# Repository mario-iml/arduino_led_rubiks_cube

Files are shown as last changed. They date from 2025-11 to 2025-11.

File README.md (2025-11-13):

# arduino_led_rubiks_cube
Disclaimer: This was in 2019, and we didn't even know about Git yet, so we had to scrape together Code and PCB files from old chats. We take no guarantee that this works and is up-to-date :).

## Description
Arduino based LED Rubik's Cube. 
This Project was made as a High-school Project with two other Students. To achieve this, we had to:
- Design of PCB's encompassing the buttons, LED's and shift registers with EAGLE
- Designing and Printing of the cubes case
- Assembling and Wirering the PCB's and Arduino
- Write the Code in Arduino IDE with C++

## Problems we encountered
- We were all pretty new to Computer Science and Electrical Engineering. We made many mistakes but learned many things in the process.
- We accidentally ordered the wrong type of LEDs (common anode instead of common cathode) for the PCB without realizing it. In the end, we had to desolder some of the LEDs again :(
- There were mistakes in the first version of the PCB design, which caused us to get dangerously close to the deadline due to long delivery times.

## PCB designs
The PCBs were designed with the Eagle software. Design files can be found in the Repo and here are some Screenshots:





## Other Images






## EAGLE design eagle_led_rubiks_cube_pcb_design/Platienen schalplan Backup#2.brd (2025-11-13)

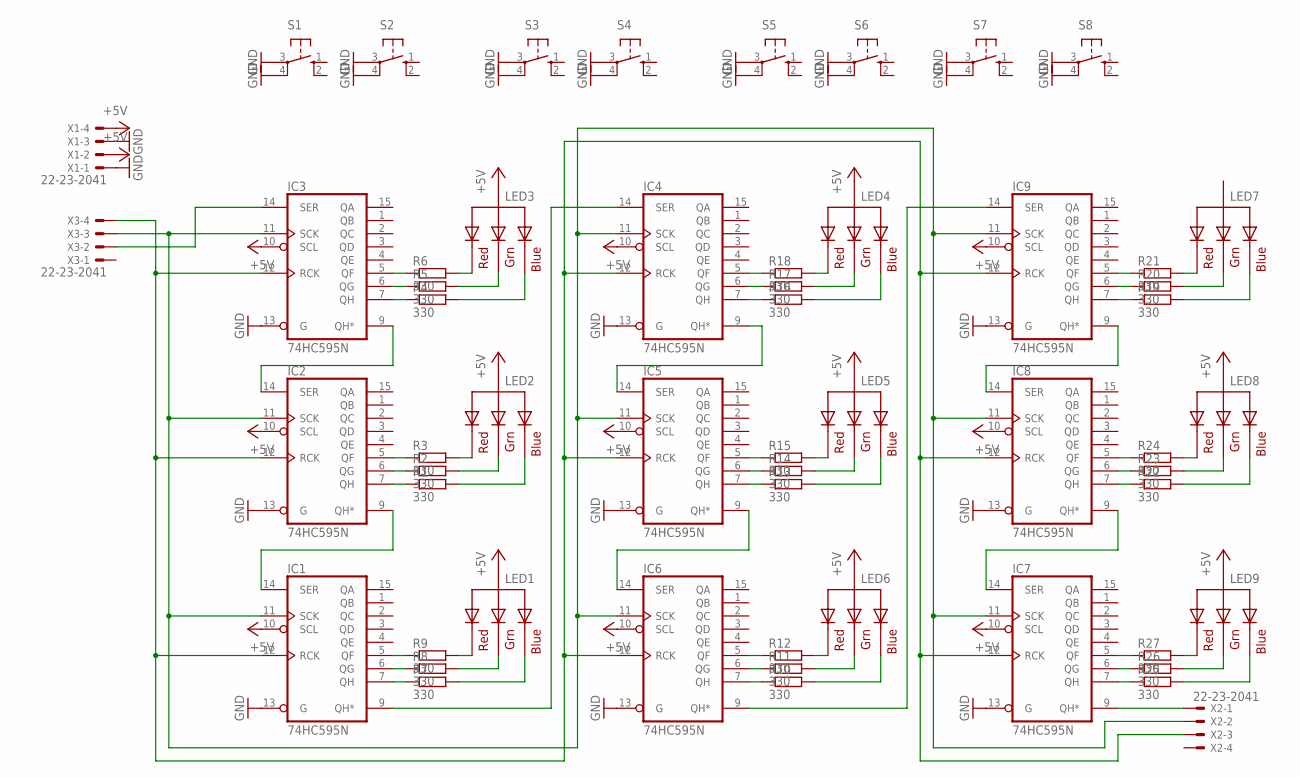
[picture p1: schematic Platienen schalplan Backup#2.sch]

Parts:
IC1, IC2, IC3, IC4, IC5, IC6, IC7, IC8, IC9: 74HC595N; DIL16
LED1, LED2, LED3, LED4, LED5, LED6, LED7, LED8, LED9: RGBLED_CA-5MM; LED5MMRGB
R1, R2, R3, R4, R5, R6, R7, R8, R9, R10, R11, R12, R13, R14, R15, R16, R17, R18, R19, R20, R21, R22, R23, R24, R25, R26, R27: 330; 0204/5
S1, S2, S3, S4, S5, S6, S7, S8: 10-XX; B3F-10XX
X1, X2, X3: 22-23-2041

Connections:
+5V: IC1.10 (SCL), IC2.10 (SCL), IC3.10 (SCL), IC4.10 (SCL), IC5.10 (SCL), IC6.10 (SCL), IC7.10 (SCL), IC8.10 (SCL), IC9.10 (SCL), LED1.2 (VCC), LED2.2 (VCC), LED3.2 (VCC), LED4.2 (VCC), LED5.2 (VCC), LED6.2 (VCC), LED8.2 (VCC), LED9.2 (VCC), X1.2, X1.4
GND: IC1.8 (GND), IC1.13 (G), IC2.8 (GND), IC2.13 (G), IC3.8 (GND), IC3.13 (G), IC4.8 (GND), IC4.13 (G), IC5.8 (GND), IC5.13 (G), IC6.8 (GND), IC6.13 (G), IC7.8 (GND), IC7.13 (G), IC8.8 (GND), IC8.13 (G), IC9.8 (GND), IC9.13 (G), S1.3, S1.4 (P1), S2.3, S2.4 (P1), S3.3, S3.4 (P1), S4.3, S4.4 (P1), S5.3, S5.4 (P1), S6.3, S6.4 (P1), S7.3, S7.4 (P1), S8.3, S8.4 (P1), X1.1, X1.3
unnamed: IC3.7 (QH), R4.1
unnamed: IC3.6 (QG), R5.1
unnamed: IC3.5 (QF), R6.1
unnamed: LED5.1 (RED), R15.2
unnamed: LED4.1 (RED), R18.2
unnamed: LED7.1 (RED), R21.2
unnamed: IC2.7 (QH), R1.1
unnamed: IC2.6 (QG), R2.1
unnamed: IC2.5 (QF), R3.1
unnamed: IC1.5 (QF), R9.1
unnamed: IC1.6 (QG), R8.1
unnamed: IC1.7 (QH), R7.1
unnamed: LED7.3 (GREEN), R20.2
unnamed: LED7.4 (BLUE), R19.2
unnamed: LED8.1 (RED), R24.2
unnamed: LED8.3 (GREEN), R23.2
unnamed: LED8.4 (BLUE), R22.2
unnamed: LED9.1 (RED), R27.2
unnamed: IC6.7 (QH), R10.1
unnamed: IC6.6 (QG), R11.1
unnamed: IC6.5 (QF), R12.1
unnamed: LED9.3 (GREEN), R26.2
unnamed: LED9.4 (BLUE), R25.2
unnamed: LED6.1 (RED), R12.2
unnamed: IC5.7 (QH), R13.1
unnamed: IC5.6 (QG), R14.1
unnamed: IC5.5 (QF), R15.1
unnamed: LED6.3 (GREEN), R11.2
unnamed: LED6.4 (BLUE), R10.2
unnamed: LED5.3 (GREEN), R14.2
unnamed: IC4.7 (QH), R16.1
unnamed: IC4.6 (QG), R17.1
unnamed: IC4.5 (QF), R18.1
unnamed: LED5.4 (BLUE), R13.2
unnamed: LED4.3 (GREEN), R17.2
unnamed: LED4.4 (BLUE), R16.2
unnamed: IC9.7 (QH), R19.1
unnamed: IC9.6 (QG), R20.1
unnamed: IC9.5 (QF), R21.1
unnamed: IC8.5 (QF), R24.1
unnamed: IC8.6 (QG), R23.1
unnamed: IC8.7 (QH), R22.1
unnamed: IC7.5 (QF), R27.1
unnamed: IC7.6 (QG), R26.1
unnamed: IC7.7 (QH), R25.1
unnamed: LED2.1 (RED), R3.2
unnamed: LED2.3 (GREEN), R2.2
unnamed: LED2.4 (BLUE), R1.2
unnamed: LED1.1 (RED), R9.2
unnamed: LED1.3 (GREEN), R8.2
unnamed: LED1.4 (BLUE), R7.2
unnamed: LED3.1 (RED), R6.2
unnamed: LED3.3 (GREEN), R5.2
unnamed: IC2.14 (SER), IC3.9 (QH*)
unnamed: IC1.14 (SER), IC2.9 (QH*)
unnamed: IC1.9 (QH*), IC4.14 (SER)
unnamed: IC4.9 (QH*), IC5.14 (SER)
unnamed: IC5.9 (QH*), IC6.14 (SER)
unnamed: IC6.9 (QH*), IC9.14 (SER)
unnamed: IC8.14 (SER), IC9.9 (QH*)
unnamed: IC7.14 (SER), IC8.9 (QH*)
unnamed: IC1.12 (RCK), IC2.12 (RCK), IC3.12 (RCK), IC4.12 (RCK), IC5.12 (RCK), IC6.12 (RCK), IC7.12 (RCK), IC8.12 (RCK), IC9.12 (RCK), X2.3, X3.4
unnamed: IC3.14 (SER), X3.2
unnamed: IC1.11 (SCK), IC2.11 (SCK), IC3.11 (SCK), IC4.11 (SCK), IC5.11 (SCK), IC6.11 (SCK), IC7.11 (SCK), IC8.11 (SCK), IC9.11 (SCK), X2.2, X3.3
unnamed: IC7.9 (QH*), X2.1
unnamed: LED3.4 (BLUE), R4.2
VCC: IC1.16 (VCC), IC2.16 (VCC), IC3.16 (VCC), IC4.16 (VCC), IC5.16 (VCC), IC6.16 (VCC), IC7.16 (VCC), IC8.16 (VCC), IC9.16 (VCC)

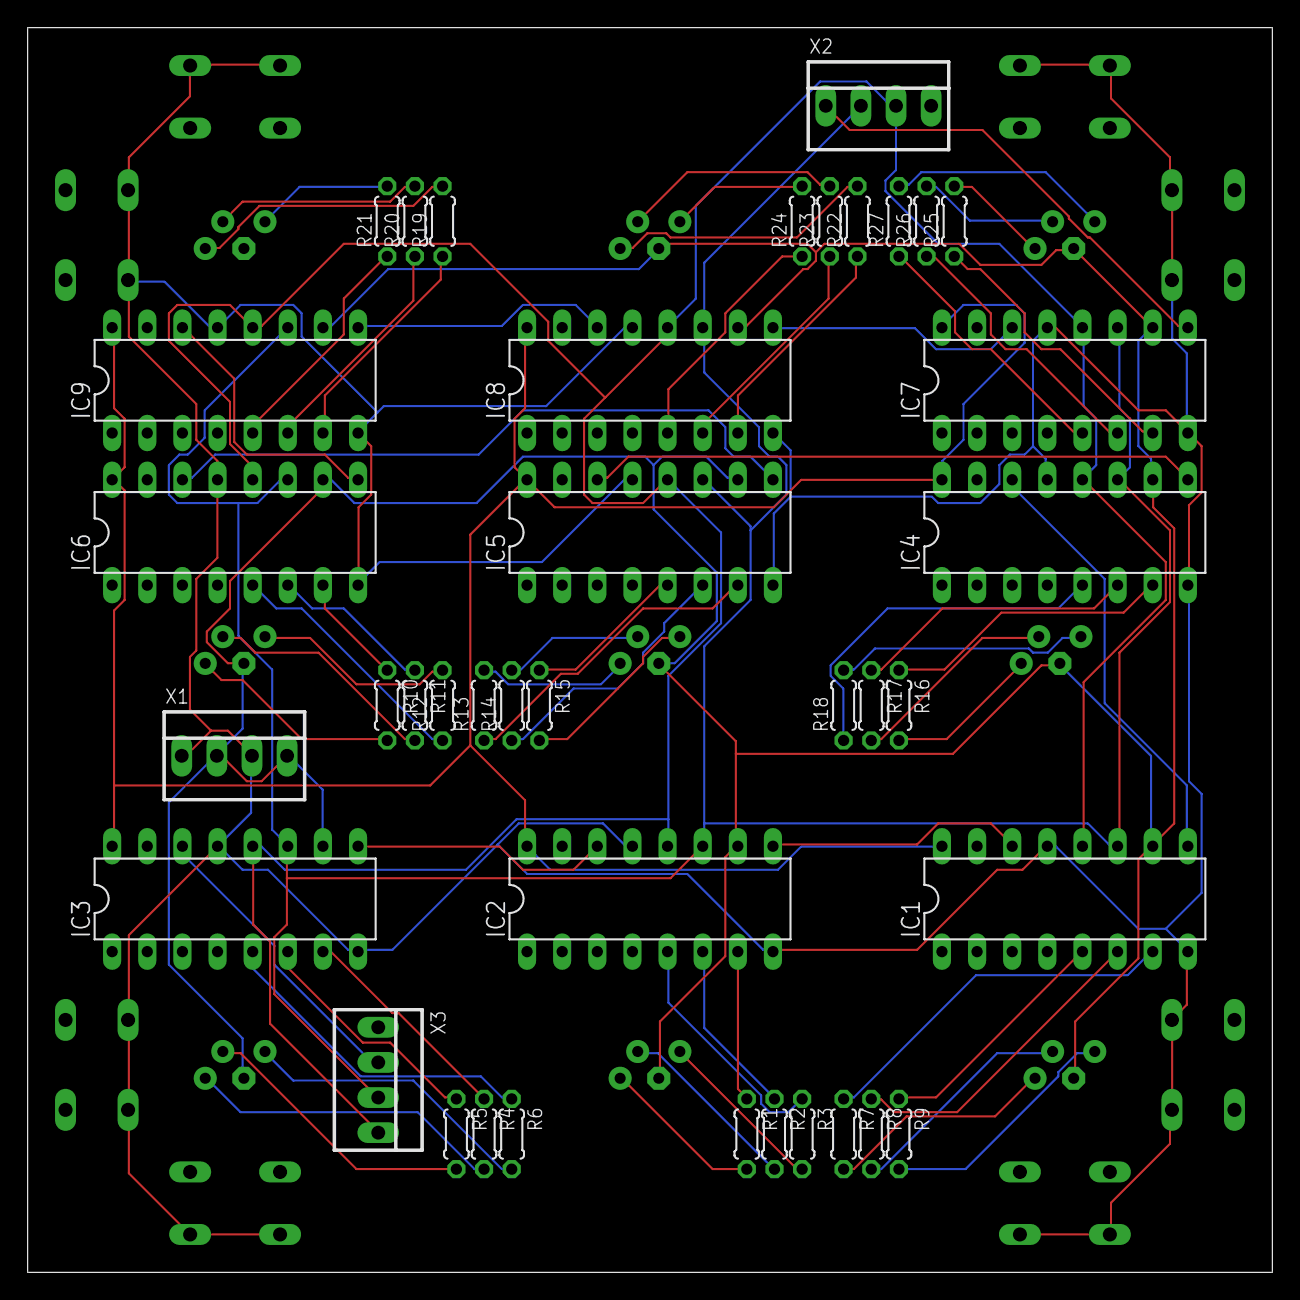
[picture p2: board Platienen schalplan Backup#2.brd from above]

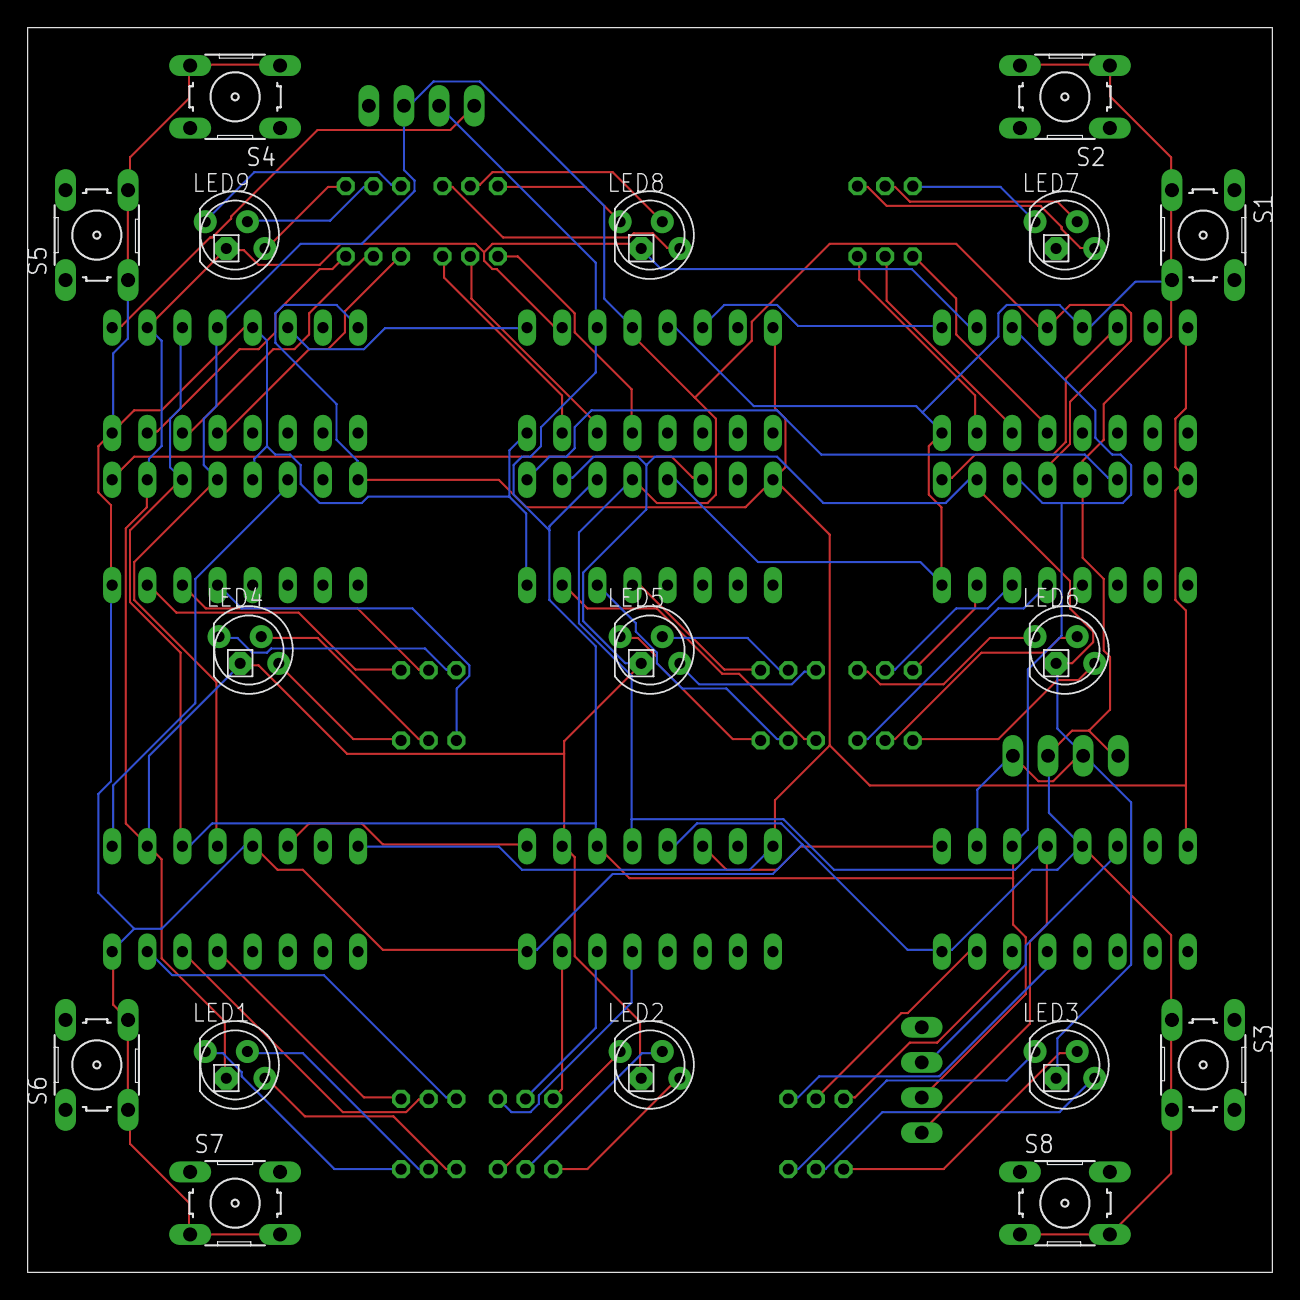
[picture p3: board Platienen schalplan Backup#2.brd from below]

Board: 2 copper layers, 90.0 x 90.0 mm, 56 parts (17 on the bottom side), 69 nets.

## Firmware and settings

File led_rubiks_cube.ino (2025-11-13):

// This code was recovered from a project documentation and IS NOT COMPLETE. We sadly dont have the whole code anymore
int datapin=11; //Pin 11 des Arduino ist an den data input(DS) des Schieberegisters angeschlossen
int clockpin=12; //Pin 12 des Arduino ist an den clock Pin(SH_CP) des Schieberegisters angeschlossen
int latchpin=8; //Pin 8 des Arduino ist an den latch Pin(ST_CP) des Schieberegisters angeschlossen

byte ledB=B011; //Farbe Blau
byte ledG=B101; //Farbe Grün
byte ledR=B110; //Farbe Rot
byte ledV=B010; //Farbe Violet
byte ledY=B100;  //Farbe Gelb
byte ledT=B001;  //Farbe Türkis
byte ledW=000;  //Farbe Weiß
byte led0=111;   //Farbe Aus

//Erstellen einer Array mit allen 54 LEDs und deren standardmäßig sortierter Anordnung, diese wird dann bei den Knopfdrücken verändert z.B. leds[54] = leds[53]
byte leds[]={ledR,ledR,ledR,ledR,ledR,ledR,ledR,ledR,ledR,ledW,ledW,ledW,ledW,ledW,ledW,ledW,ledW,ledW,ledB,ledB,ledB,ledB,ledB,ledB,ledB,ledB,ledB,ledG,ledG,ledG,ledG,ledG,ledG,ledG,ledG,ledG,ledY,ledY,ledY,ledY,ledY,ledY,ledY,ledY,ledY,ledV,ledV,ledV,ledV,ledV,ledV,ledV,ledV,ledV};

//Temporäre Variablen für den Tausch der leds
byte t0=leds[45],t1=leds[46],t2=leds[47],t3=leds[48],t4=leds[49],t5=leds[50],t6=leds[51],t7=leds[52],t8=leds[53],b0=leds[36],b1=leds[37],b2=leds[38],b3=leds[39],b4=leds[40],b5=leds[41],b6=leds[42],b7=leds[43],b8=leds[44],d0=leds[27],d1=leds[28],d2=leds[29],d3=leds[30],d4=leds[31],d5=leds[32],d6=leds[33],d7=leds[34],d8=leds[35],l0=leds[18],l1=leds[19],l2=leds[20],l3=leds[21],l4=leds[22],l5=leds[23],l6=leds[24],l7=leds[25],l8=leds[26],f0=leds[9],f1=leds[10],f2=leds[11],f3=leds[12],f4=leds[13],f5=leds[14],f6=leds[15],f7=leds[16],f8=leds[17],r0=leds[0],r1=leds[1],r2=leds[2],r3=leds[3],r4=leds[4],r5=leds[5],r6=leds[6],r7=leds[7],r8=leds[8];

const int bpin[]={5,6,7,8,9,10,11,12,13,A0,A1,A2}; //Arry mit den verschiedenen möglichen Moves mit den Buttons

int wait=500; //variable für eine festgelegte Wartedauer(kann einfach für den gesamten Code verändert werden

void setup()
{

    pinMode(datapin, OUTPUT); //Pins auf Output stellen("Daten senden")
    pinMode(clockpin, OUTPUT); //Pins auf Output stellen("Daten senden") 
    pinMode(latchpin, OUTPUT); //Pins auf Output stellen("Daten senden")
 
    for (int i=0;i<12;i++) //Wird für alle 12 möglichen Moves widerholt
    {
        pinMode(bpin[i],INPUT); //bpin[i]/alle möglichen Pins für die Knöpfe auf INPUT, so können wir abfragen ob ein Signal kommt
        digitalWrite(bpin[i],HIGH); //bpin[i]/alle möglichen Pins für die Knöpfe werden auf HIGH gestellt
    }
 
    digitalWrite(latchpin, LOW); //Latch Pin auf LOW(aus), dass die Leds sich nicht ändern wärend neue Bits reingegeben werden
    for (int i=0; i<54;i++) //For Schleife(Der Vorgang wird für alle 54 LEDs/Schieberegister widerholt)
    { 
        shiftOut(datapin, clockpin, MSBFIRST, leds[i]);  //LEDs werde sortiert eingeschaltet(Cube geht an)
    }
    digitalWrite(latchpin, HIGH);  //Latch Pin auf HIGH(an), um die "änderungen anzuzeigen"
}

void loop()
{
    digitalWrite(latchpin,LOW);
    for(int i=0;i<54;i++) //Wird für alle 54 LEDs/Schieberegister widerholt
    { 
        shiftOut(datapin, clockpin, MSBFIRST, leds[i]); //ShiftOut Befehl wird durch loop jedes mal widerholt(somit werden Änderungen übernommen)
    }
    digitalWrite(latchpin, HIGH);

    for(int i=0;i<12;i++)
    {
        digitalWrite(bpin[i],HIGH); //Jeder mögliche Move wird nochmals auf HIGH gestellt
    }

    int b[12]; //12 Zusätzliche Variablen erstellen in denen der Status der Buttons gespeichert wird.
    for (int x=0;x<12;x++) //Schleife für jeden möglichen move
    {
        b[x]=digitalRead(bpin[x]); //Es wird der Wert in jeder Variable der Array ausgelesen
    }
    if(((b[0]==LOW))) //IF abfrage für einen move
    {
        //rotate left face CCW
        t0=leds[45],t1=leds[46],t2=leds[47],t3=leds[48],t4=leds[49],t5=leds[50],t6=leds[51],t7=leds[52],t8=leds[53],b0=leds[36],b1=leds[37],b2=leds[38],b3=leds[39],b4=leds[40],b5=leds[41],b6=leds[42],b7=leds[43],b8=leds[44],d0=leds[27],d1=leds[28],d2=leds[29],d3=leds[30],d4=leds[31],d5=leds[32],d6=leds[33],d7=leds[34],d8=leds[35],l0=leds[18],l1=leds[19],l2=leds[20],l3=leds[21],l4=leds[22],l5=leds[23],l6=leds[24],l7=leds[25],l8=leds[26],f0=leds[9],f1=leds[10],f2=leds[11],f3=leds[12],f4=leds[13],f5=leds[14],f6=leds[15],f7=leds[16],f8=leds[17],r0=leds[0],r1=leds[1],r2=leds[2],r3=leds[3],r4=leds[4],r5=leds[5],r6=leds[6],r7=leds[7],r8=leds[8];
        leds[51]=leds[15];
        leds[50]=leds[14];
        leds[45]=leds[9];
        leds[42]=t6;
        leds[41]=t5;
        leds[36]=t0;
        leds[33]=b6;
        leds[32]=b5;
        leds[27]=b0;
        leds[15]=d6;
        leds[14]=d5;
        leds[9]=d0;
        leds[26]=leds[24];
        leds[21]=leds[25];
        leds[20]=l8;
        leds[19]=l3;
        leds[18]=l2;
        leds[23]=l1;
        leds[24]=l0;
        leds[25]=l5;
        delay(wait);
    }
    // ... other Moves
}

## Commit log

2025-11-13 Update README with project details and images
    Added detailed project description, problems encountered, and PCB design information.
2025-11-13 adding pcb design files and part of the code we could recover. NOT COMPLETE
    [Platienen schalplan Backup#2.brd, Platienen schalplan Backup#2.sch]
